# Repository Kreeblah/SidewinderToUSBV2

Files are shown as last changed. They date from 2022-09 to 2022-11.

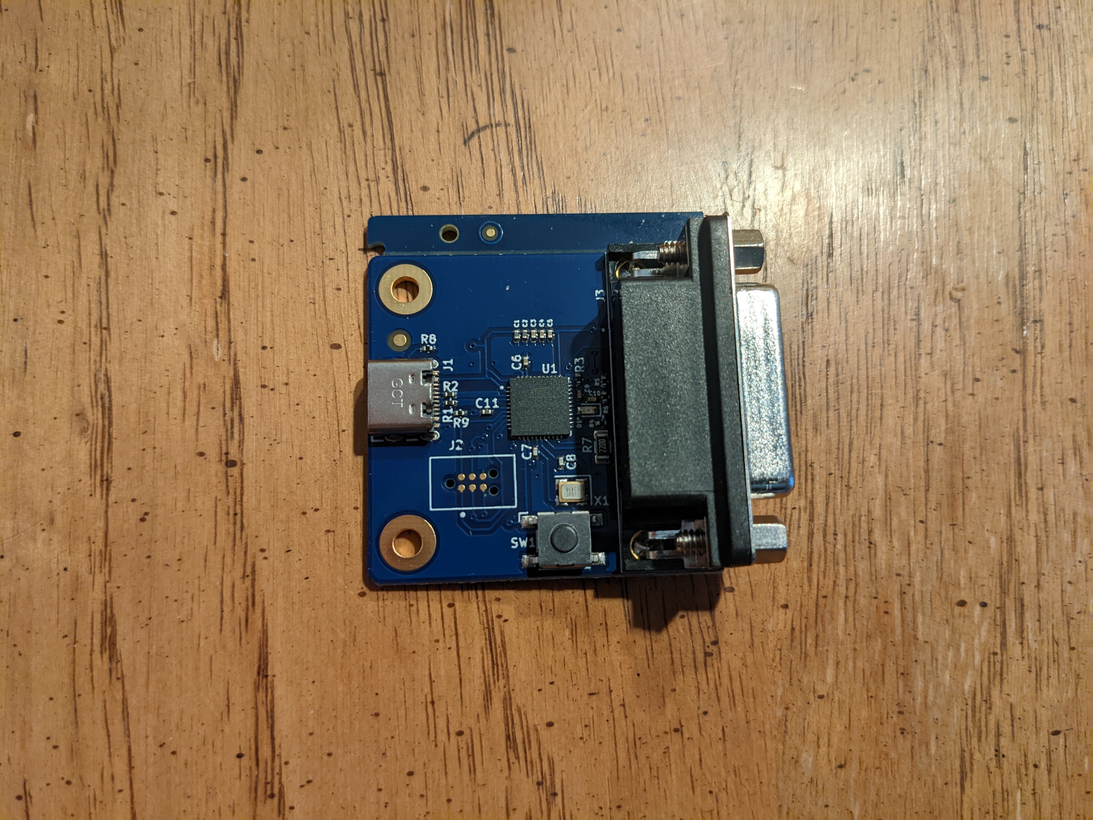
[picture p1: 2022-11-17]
Board_Front.jpg

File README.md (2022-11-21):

# SidewinderToUSBV2 (USB C version)
**NOTE:** The only BOM which has been actually manufactured and tested is the DigiKey BOM with PCBWay.  The other BOMs are available for convenience/reference, but should be double-checked for accuracy and compliance with assembly house requirements.

**NOTE 2:** The current parts shortage means that the microcontroller used in this design is in short supply.  I have successfully tested the design with an ATmega32u4RC-MU substituted for the original ATmega32u4-MU.  No changes need to be made to the programming or board design to substitute the part in.

This project is an integrated Sidewinder adaptor, which includes assembly files for various manufacturers.  This project originated as a combination of [the adapt-ffb-joy project](https://github.com/tloimu/adapt-ffb-joy) (minus the trim pots) with the [Teensy 2.0](https://www.pjrc.com/teensy/schematic.html) in order to remove the requirement for a comparatively expensive Teensy module and to make manufacture by a professional facility easier, with the intent of providing an open-source board that people can use to send off to have adaptors made.

Source code for the Sidewinder adaptor hexes can be found at [the adapt-ffb-joy project](https://github.com/tloimu/adapt-ffb-joy) and [the sw3dprousb project](https://code.google.com/archive/p/sw3dprousb/).  Programming can be done using a [Tag-Connect TC2030-IDC-NL](https://www.tag-connect.com/product/tc2030-idc-nl) and an AVR programmer capable of programming a Microchip (formerly Atmel) ATmega32U4 such as the [Pololu AVR Programmer v2.1](https://www.pololu.com/product/3172).

Licensing for the board is Creative Commons Attribution-ShareAlike 4.0 (CC BY-SA 4.0).

# Firmware

To use with various Sidewinder devices, there are three .hex files provided.  Only one of them can be flashed to the microcontroller at a time, so which one to use depends on which device you'll be using the adaptor with:

- 3DPro32u4-10.hex - Sidewinder Precision Pro, 3D Pro, 3D Pro Plus, or Force Feedback Pro (without force feedback support)
- adaptffbjoy-r54.hex - Sidewinder Force Feedback Pro (with force feedback support)
- adaptffbjoy-r54-patched.hex - Same as adaptffbjoy-r54.hex plus [some additional patches](https://github.com/Kreeblah/adapt-ffb-joy) (FFB strength calculation and a fix for the shift button)
- adaptffbjoy-r54-JayBee.hex - Another alternative patch set for adaptffbjoy-r54.hex, sourced from https://github.com/JayBee-git/adapt-ffb-joy
- Wheel.hex - Sidewinder Force Feedback Wheel

# Hardware

Schematic and PCB files for the board are provided in KiCad format.

Gerbers and POS files (for component placement) are included in the Production directory.  Note that the USB lines were calculated assuming 1 oz copper thickness.

BOMs for various assembly houses are also included in the Production directory.  All of the parts listed in the BOMs are RoHS-compliant.

Important components for users to be aware of are J1 (the USB C port), J3 (the gameport), and SW1 (the reset button).  For people who have these built themselves, J2 is the block of pads used for programming the AVR.

# Known Issues

- Some people have seen issues with FFB sticks sometimes not properly using FFB effects or getting stuck, even using the FFB-specific firmware.  For other people, though, it works fine.  I've been able to replicate the issue both on this adaptor and on one which uses the original Teensy 2.0-based design, so the behavior is at least consistent with the original design.  Some folks have seen some FFB improvements with Teensy 2.0-based designs by replacing one of 1nF capacitors with 1.5nF capacitors (C2 on the original schematic), but I haven't seen the same improvements when making the same change this board.  I'll need to test out other capacitance values and see whether any of them yield similar improvements on this design.
- Sometimes, people see some jitter between a couple of values in the X and Y axes when the stick isn't being touched.  This is an issue that exists both with this adaptor and the original design, as it's a firmware issue.  These adaptors report exactly what the joystick sends for data, which includes that jitter that some people observe.  A fix for this would require a firmware update to account for it in software, at which point, it would be fixed in these adaptors and the original adaptors.
- adaptffbjoy-r54.hex doesn't use the shift button properly.  It's supposed to act as a meta button to turn the eight other buttons into an effective sixteen buttons (one button with shift not pressed, and a different one with shift pressed), however it acts as a ninth button instead of a modifier for other buttons.  adaptffbjoy-r54-patched.hex includes a patch to fix this.

# Programming

## General

**Note:** The board should be disconnected from USB and from your joystick while programming it via an ISP.  To power it during programming, make sure your programmer is set to output 5V.

Programming the board using the above combo of programmer and connector can be done with [AVRDUDE](https://www.nongnu.org/avrdude/).  Fuses should be set to [low: 5F, high: 99, extended: C4, lockbit: FF](http://eleccelerator.com/fusecalc/fusecalc.php?chip=atmega32u4&LOW=5F&HIGH=99&EXTENDED=C4&LOCKBIT=FF).

If you're using the Pololu programmer mentioned above, then in order to get the path to the port your programmer is on, you can do this:

    pavr2cmd --prog-port

This will return a device port path which can be used as a parameter to AVRDUDE to program your board.

Regardless of which programmer you use, though, you'll need the path to your device, which you can then use with AVRDUDE:

    avrdude -c YOUR_PROGRAMMER_TYPE -P YOUR_DEVICE_PORT_PATH -p atmega32u4 -U flash:w:YOUR_HEX_FILE:i

In this example, `YOUR_HEX_FILE` could be one of the firmware files or the hex file for a bootloader.

If you're unsure of what value to use for `-c`, check with your programmer documentation.  If you need a list of what programmers are supported, you can use:

    avrdude -c ?

If you're using the Pololu programmer, you can combine the two above commands via a subcommand in bash, zsh, ksh, etc.:

    avrdude -c stk500v2 -P $(pavr2cmd --prog-port) -p atmega32u4 -U lfuse:w:0x5f:m -U hfuse:w:0x99:m -U efuse:w:0xc4:m -U flash:w:YOUR_HEX_FILE:i

Or, for csh:

    avrdude -c stk500v2 -P `pavr2cmd --prog-port` -p atmega32u4 -U lfuse:w:0x5f:m -U hfuse:w:0x99:m -U efuse:w:0xc4:m -U flash:w:YOUR_HEX_FILE:i

Or fish:

    avrdude -c stk500v2 -P (pavr2cmd --prog-port) -p atmega32u4 -U lfuse:w:0x5f:m -U hfuse:w:0x99:m -U efuse:w:0xc4:m -U flash:w:YOUR_HEX_FILE:i

## Using a bootloader

If you'd prefer to use a bootloader rather than flashing a firmware file directly to the flash area, you can flash any ATMega32U4-compatible bootloader you like via an ISP.  This will allow for changing which firmware file is being used via the board's USB connection, rather than needing to connect an ISP again, but may result in longer boot times.  So far, only the [LUFA](https://github.com/abcminiuser/lufa) CDC bootloader has been tested, which is included in the `Bootloader` directory of this project, but other bootloaders are likely to work.

If using the LUFA CDC bootloader, when the board is connected to a USB port, press and release the reset button (labeled SW1 on the board) to reset into the bootloader.  At this point, avrdude can be used to flash the firmware file of your choice (shown below as `YOUR_HEX_FILE`) with the following command:

    avrdude -p atmega32u4 -c avr109 -P YOUR_DEVICE_PORT -U flash:w:YOUR_HEX_FILE:i

**Note:** `YOUR_DEVICE_PORT` is the port which the board shows up on when in bootloader mode.  On macOS, this will be a /dev/tty.usbmodem device (e.g. `/dev/tty.usbmodem14201`).  On Windows, it's likely to be a COM port.  On Linux, it should be somewhere in the /dev/ttyACM device list (e.g. `/dev/ttyACM0`).

### LUFA CDC Compilation Options

If you'd like to compile your own copy of the LUFA CDC bootloader, you can get the source code [here](https://github.com/abcminiuser/lufa).  The CDC bootloader code is in the `Bootloaders/CDC` directory, where there's a makefile.  If you have the AVR GCC toolchain installed, you can build the bootloader by editing the makefile to use the following settings (leaving the other settings as is):

    MCU = atmega32u4
    ARCH = AVR8
    BOARD = TEENSY2
    F_CPU = 16000000
    F_USB = $(F_CPU)
    FLASH_SIZE_KB = 32
    BOOT_SECTION_SIZE_KB = 4

At that point, if you have the AVR GCC toolchain installed properly, running `make` should go through the build and generate a file named `BootloaderCDC.hex` which you can flash as your bootloader using an ISP.

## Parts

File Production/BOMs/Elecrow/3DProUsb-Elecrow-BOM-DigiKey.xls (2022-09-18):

3DProUsb BOM
Part | Value | Device | Package | Qty | Description | Remark
J1 | USB C PORT | USB C PORT | HYBRID SMD/THRU-HOLE | 1 | CONN RCP USB2.0 TYP C 24P SMD RA | GCT USB4105-GF-A
J2 | N/A | N/A | N/A | 1 | DO NOT POPULATE - NOT A PART | Tag-Connect TC2030-NL-FP
J3 | FEMALE | DA15 CONNECTOR | 15POS | 1 | D-SUB R/A 15 WAY SOCKET | Adam Tech DA15-SL-25
U1 | ATMEGA32U4-MU | ATMEGA32U4-MU | QFN50P700X700X100-45N | 1 | IC MCU 8BIT 32KB FLASH 44VQFN | Microchip ATMEGA32U4-MU
X1 | 16.00 MHZ, 10PF LOAD CAPACITANCE | CLOCK CRYSTAL | SMD | 1 | CRYSTAL 16.00 MHZ 10PF SMD | EPSON FA-238 16.0000MB-K3
SW1 | PUSH-BUTTON SWITCH | PUSH-BUTTON SWITCH | SMD | 1 | SWITCH TACTILE SPST-NO 0.05A 24V | Omron Electronics Inc-EMC Div B3FS-1000P
D1 | GREEN | LED | 0603 | 1 | LED GREEN CLEAR SMD | Lite-On Inc. LTST-C191KGKT
C1,C2,C11 | 1UF, 16V | CERAMIC CAPACITOR | 0402 | 3 | CAP CER 1UF 16V X5R 0402 | Taiyo Yuden EMK105BJ105KV-F
C3,C4,C5,C6 | 0.1UF, 25V | CERAMIC CAPACITOR | 0402 | 4 | CAP CER 0.1UF 25V X7R 0402 | Taiyo Yuden TMK105B7104KV-FR
C7,C8 | 10PF, 50V | CERAMIC CAPACITOR | 0402 | 2 | CAP CER 10PF 50V NP0 0402 | Taiyo Yuden UMK105CG100DV-F
C9,C10 | 1000PF, 50V | CERAMIC CAPACITOR | 0402 | 2 | CAP CER 1000PF 50V X7R 0402 | Taiyo Yuden UMK105B7102KV-F
R1,R2 | 22 OHM, 1%, 1/16W | THICK FILM RESISTOR | 0402 | 2 | RES SMD 22 OHM 1% 1/16W 0402 | Bourns Inc. CR0402-FX-22R0GLF
R3,R4 | 1 KOHM, 1%, 1/16W | THICK FILM RESISTOR | 0402 | 2 | RESTHINFILM 0402 1K00 1% 63MW TC | Bourns Inc. CRT0402-FZ-1001GST
R5,R6 | 2.2 KOHM, 5%, 1/16W | THICK FILM RESISTOR | 0402 | 2 | RES SMD 2.2K OHM 5% 1/16W 0402 | Bourns Inc. CR0402-JW-222GLF
R7 | 220 OHM, 1%, 1/4W | THICK FILM RESISTOR | 1206 | 1 | RES SMD 220 OHM 1% 1/4W 1206 | Bourns Inc. CR1206-FX-2200ELF
R8, R9 | 5.1 KOHM 0.1% 1/16W | THICK FILM RESISTOR | 0402 | 2 | RES SMD 5.1K OHM 0.1% 1/16W 0402 | Panasonic Electronic Components ERA-2APB512X

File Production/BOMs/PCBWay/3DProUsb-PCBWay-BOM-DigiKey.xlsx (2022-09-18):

 |  |  | Sidewinder To USB BOM
Item # | *Designator | *Qty | Manufacturer | *Mfg Part # | Description / Value | *Package/Footprint | Type | Your Instructions / Notes
1 | J1 | 1 | GCT | USB4105-GF-A | CONN RCP USB2.0 TYP C 24P SMD RA | SMD | HYBRID | DigiKey Part: 2073-USB4105-GF-ADKR-ND
2 | J2 | 1 | Tag-Connect | TC2030-NL-FP | DO NOT POPULATE - NOT A PART | N/A | N/A | DO NOT POPULATE - NOT A PART
3 | J3 | 1 | Adam Tech | DA15-SL-25 | D-SUB R/A 15 WAY SOCKET | 15POS | THRU-HOLE | DigiKey Part: 2057-DA15-SL-25-ND
4 | U1 | 1 | Microchip Technology | ATMEGA32U4-MU | IC MCU 8BIT 32KB FLASH 44VQFN | SMD | SMD | DigiKey Part: ATMEGA32U4-MU-ND
5 | X1 | 1 | EPSON | FA-238 16.0000MB-K3 | CRYSTAL 16.00 MHZ 10PF SMD | SMD | SMD | DigiKey Part: SER4046CT-ND
6 | SW1 | 1 | Omron Electronics Inc-EMC Div | B3FS-1000P | SWITCH TACTILE SPST-NO 0.05A 24V | SMD | SMD | DigiKey Part: SW423CT-ND
7 | D1 | 1 | Lite-On Inc. | LTST-C191KGKT | LED GREEN CLEAR SMD | 0603 | SMD | DigiKey Part: 160-1446-1-ND
8 | C1,C2,C11 | 3 | Taiyo Yuden | EMK105BJ105KV-F | CAP CER 1UF 16V X5R 0402 | 0402 | SMD | DigiKey Part: 587-2477-1-ND
9 | C3,C4,C5,C6 | 4 | Taiyo Yuden | TMK105B7104KV-FR | CAP CER 0.1UF 25V X7R 0402 | 0402 | SMD | DigiKey Part: 587-5476-1-ND
10 | C7,C8 | 2 | Taiyo Yuden | UMK105CG100DV-F | CAP CER 10PF 50V NP0 0402 | 0402 | SMD | DigiKey Part: 587-1947-1-ND
11 | C9,C10 | 2 | Taiyo Yuden | UMK105B7102KV-F | CAP CER 1000PF 50V X7R 0402 | 0402 | SMD | DigiKey Part: 587-1220-1-ND
12 | R1,R2 | 2 | Bourns Inc. | CR0402-FX-22R0GLF | RES SMD 22 OHM 1% 1/16W 0402 | 0402 | SMD | DigiKey Part: CR0402-FX-22R0GLFCT-ND
13 | R3,R4 | 2 | Bourns Inc. | CRT0402-FZ-1001GST | RESTHINFILM 0402 1K00 1% 63MW TC | 0402 | SMD | DigiKey Part: CRT0402-FZ-1001GSTCT-ND
14 | R5,R6 | 2 | Bourns Inc. | CR0402-JW-222GLF | RES SMD 2.2K OHM 5% 1/16W 0402 | 0402 | SMD | DigiKey Part: CR0402-JW-222GLFCT-ND
15 | R7 | 1 | Bourns Inc. | CR1206-FX-2200ELF | RES SMD 220 OHM 1% 1/4W 1206 | 1206 | SMD | DigiKey Part: CR1206-FX-2200ELFCT-ND
16 | R8, R9 | 2 | Panasonic Electronic Components | ERA-2APB512X | RES SMD 5.1K OHM 0.1% 1/16W 0402 | 0402 | SMD | DigiKey Part: P5.1KCNDKR-ND
Need a quick and accurante quote? Need an efficient production? Please read SMT Ordering Necessary Files & Info in 1 minute. Thank you very much! (https://www.pcbway.com/smt_ordering_guide.html)
Click for Instructions on How to Create a BOM (https://www.pcbway.com/blog/PCB_Assembly/How_to_Build_a_BOM__Bill_Of_Materials_.html)

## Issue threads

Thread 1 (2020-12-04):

Boards to purchase

AGTDesigns, 2020-12-04:
Hi! Do you still have boards to sell? I have a Sidewinder FFB Wheel with gameport that I would like to use with Win10, do you think it might work? How much would the board cost?
Thanks a lot!

Kreeblah, 2020-12-04:
I do still have some to sell, yes.

This hardware should be completely compatible with the original design, so I'd imagine it works as well as it would on the original adaptor (working except for the force feedback functionality), but since I don't own an FFB Wheel, I don't really have the means to test it myself.

If you're still interested in one or if you have some more questions, feel free to send me an e-mail.  You can reach me via the same username as here at Gmail.

Closed 2020-12-04.

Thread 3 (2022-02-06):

Jitter on all axes on FFB Pro, but only with FFB active - perhaps EU 60hz power?

KTeichel, 2022-02-06:
Hi,

I'm one of those using the adapter for an old Sidewinder Force Feedback Pro, and (like other users) I get visible jitter on all of the axes unless they are fully deflected.

I wanted to share my observations about this, so that hopefully it can help find a fix eventually.
I noticed that the jitter only happens with the power supply plugged in.
Being located in Germany, I thought that it might have something to do with the power line frequency being different in US (60hz) vs mostly the rest of the world (50hz); I haven't looked at a 60 vs 50 hz oscillation in comparison though.
On closer inspection, it is not simply the PSU being plugged in, it seems to be rather the question of whether or not Force Feedback is actually active: if I toggle everything (including spring center) off in a utility software, the jitter goes away.
The only effect where the jitter isn't always visible (not visible when I don't touch the stick, that is) is "friction" - I don't know how motor activation works for different effects, but maybe that tells us something?

Anyway, best regards and I hope this can be of any help.

NolanNicholson, 2023-01-26:
This issue is seemingly common to all Force Feedback Pro joysticks. I live in the US, and my stick behaves the same way. Others have even tested the joystick on a native Gameport card and found the same exact behavior - axis values jitter whenever the FFB motors are on.

It's unclear whether this is the result of aging (in which case it has occurred surprisingly consistently with basically all of these joysticks), or whether this jitter was always present and nobody originally noticed it. In any case, the USB adapter is highly unlikely to be at fault.

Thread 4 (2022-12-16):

buy them

Soliver84, 2022-12-16:
Hello I read here:
Alexhttps://www.descentbb.net/viewtopic.php?p=389914#p389914

That you still have some if you still have 2 pieces, I would like to buy them, starting with the best firmware.
I live in Germany and would of course pay for the shipping. PayPal.

Thaks
Alex

Kreeblah, 2022-12-20:
Hi there!

I do still have some, but unfortunately I had to stop shipping to the EU last year.  The new rule that took effect on 1 July 2021 requires that any packages sent to the EU have VAT already collected by a registered entity, and the paperwork involved in registering to collect VAT on behalf of the EU doesn't really make sense for me.

That said, if you contact rage76 in that thread, he's located in Germany, and may have some left.

Thanks!

Soliver84, 2022-12-21:
Unfortunately I don't have access to the forum because I can't manage the security question.

If you send it as a gift or test board, no tax will be charged.

or you can ask the user for me. please i need your help

Thanks

Closed 2022-12-20.

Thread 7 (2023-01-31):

[REQUEST] Compatibility with Necroware's GamePort Adapter firmware

Hedda, 2023-01-31:
Please consider looking into adding firmware compatibility or a firmware fork of Necroware's GamePort Adapter firmware:

https://github.com/necroware/gameport-adapter

https://github.com/necroware/gameport-adapter/blob/main/README.md

https://github.com/necroware/gameport-adapter/tree/main/firmware/gameport-adapter

Necroware's GamePort Adapter firmware does not yet support Force Feedback (though someone as recently started working on that for the Necroware's GamePort Adapter hardware), but it does have other advantages, such as being fully open-source licensed under the GPL-3.0 license and including support for many other retro joysticks and gamepads.

The downside to Necroware's GamePort Adapter firmware is that it currently requires the hardware to have a DIP-switch for changing controller mode, which is something that I do not personally think is a bad idea, however might be solved in a other manor, or otherwise add a DIP-switch to your next board design?

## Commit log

2020-09-05 Initial commit with PCBWay production files
    [3DProUsb-B_Cu.gbr, 3DProUsb-B_Mask.gbr, 3DProUsb-B_Paste.gbr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]
2020-09-05 Added fiducials and additional ground plate under microcontroller
    [3DProUsb-B_Cu.gbr, 3DProUsb-B_Mask.gbr, 3DProUsb-B_Paste.gbr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]
2020-09-05 Further extended ground pour
    [3DProUsb-B_Cu.gbr, 3DProUsb-B_Mask.gbr, 3DProUsb-B_Paste.gbr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]
2020-09-05 Removed travel distance for ground signals
    [3DProUsb-B_Cu.gbr, 3DProUsb-B_Mask.gbr, 3DProUsb-B_Paste.gbr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]
2020-09-05 Added stitching vias
    [3DProUsb-B_Cu.gbr, 3DProUsb-B_Mask.gbr, 3DProUsb-B_Paste.gbr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]
2020-09-05 Turned top layer into additional ground plane and added no connect labels to unused clock pins
    [3DProUsb-B_Cu.gbr, 3DProUsb-B_Mask.gbr, 3DProUsb-B_Paste.gbr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]
2020-09-05 Added ZIP of POS files and renamed Gerber ZIP
2020-09-06 Added production silkscreen
    [3DProUsb-B_Cu.gbr, 3DProUsb-B_Mask.gbr, 3DProUsb-B_Paste.gbr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]
2020-09-07 Added more explicit marking for LED polarity
    [3DProUsb-B_Cu.gbr, 3DProUsb-B_Mask.gbr, 3DProUsb-B_Paste.gbr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]
2020-09-07 Made LED polarity more explicit
    [3DProUsb-B_Cu.gbr, 3DProUsb-B_Mask.gbr, 3DProUsb-B_Paste.gbr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]
2020-09-09 Rounded the corners on the PCB
    [3DProUsb-B_Cu.gbr, 3DProUsb-B_Mask.gbr, 3DProUsb-B_Paste.gbr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]
2020-09-10 Added BOM for Seeed Studio
    [3DProUsb-SeeedStudio-BOM.xlsx]
2020-09-10 Added BOMs for Makerfabs and OSpcb
    [3DProUsb-Makerfabs-BOM.xlsx, 3DProUsb-OSpcb-BOM.xlsx]
2020-09-10 Moved BOMs to BOMs directory
    [3DProUsb-Makerfabs-BOM.xlsx, 3DProUsb-OSpcb-BOM.xlsx, 3DProUsb-PCBWay-BOM.xlsx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]
2020-09-10 Added BOM for PCBgogo
    [3DProUsb-PCBgogo-BOM.xlsx]
2020-09-11 Added BOM for Elecrow
    [3DProUsb-Elecrow-BOM.xls]
2020-09-13 Increased VCC track width
    [3DProUsb-B_Cu.gbr, 3DProUsb-B_Mask.gbr, 3DProUsb-B_Paste.gbr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]
2020-09-21 Corrected USB port error
    [3DProUsb-B_Cu.gbr, 3DProUsb-B_Mask.gbr, 3DProUsb-B_Paste.gbr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]
2020-09-21 Replaced Gerber ZIP
2020-09-23 Connected ground pins of clock
    [3DProUsb-B_Cu.gbr, 3DProUsb-B_Mask.gbr, 3DProUsb-B_Paste.gbr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]
2020-09-24 Moved vias away from silkscreens
    [3DProUsb-B_Cu.gbr, 3DProUsb-B_Mask.gbr, 3DProUsb-B_Paste.gbr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]
2020-09-25 Made missed VCC traces thicker
    [3DProUsb-B_Cu.gbr, 3DProUsb-B_Mask.gbr, 3DProUsb-B_Paste.gbr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]
2020-09-25 Moved USB port
    [3DProUsb-B_Cu.gbr, 3DProUsb-B_Mask.gbr, 3DProUsb-B_Paste.gbr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]
2020-09-25 Updated edge cuts
    [3DProUsb-B_Cu.gbr, 3DProUsb-B_Mask.gbr, 3DProUsb-B_Paste.gbr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]
2020-09-28 Removed X2 extensions
    [3DProUsb-B_Cu.gbr, 3DProUsb-B_Mask.gbr, 3DProUsb-B_Paste.gbr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]
2020-09-29 Added soldermask window between pin pads for USB port
    [3DProUsb-B_Cu.gbr, 3DProUsb-B_Mask.gbr, 3DProUsb-B_Paste.gbr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]
2020-10-17 Added LCSC BOM for PCBWay
    [3DProUsb-PCBWay-BOM-DigiKey.xlsx, 3DProUsb-PCBWay-BOM-LCSC.xlsx]
2020-10-21 Added note in readme about current project status.
2020-10-22 Added missing component and connections
    [3DProUsb-B_Cu.gbr, 3DProUsb-B_Mask.gbr, 3DProUsb-B_Paste.gbr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]
2020-10-23 New board layout. Made things smaller, removed large trenches, and calculated USB differential impedance.
    [3DProUsb-B_Cu.gbr, 3DProUsb-B_Mask.gbr, 3DProUsb-B_Paste.gbr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]
2020-10-23 Moved a few traces further from the board edge
    [3DProUsb-B_Cu.gbr, 3DProUsb-B_Mask.gbr, 3DProUsb-B_Paste.gbr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]
2020-10-23 Moved a couple vias and silkscreens
    [3DProUsb-B_Cu.gbr, 3DProUsb-B_Mask.gbr, 3DProUsb-B_Paste.gbr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]
2020-10-25 Calculated USB trace differential impedance
    [3DProUsb-B_Cu.gbr, 3DProUsb-B_Mask.gbr, 3DProUsb-B_Paste.gbr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]
2020-10-25 Relaxed USB differential pair a bit for cheaper manufacturing.
    [3DProUsb-B_Cu.gbr, 3DProUsb-B_Mask.gbr, 3DProUsb-B_Paste.gbr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]
2020-10-25 Adjusted design rule checker and adjusted tracks for validation.
    [3DProUsb-B_Cu.gbr, 3DProUsb-B_Mask.gbr, 3DProUsb-B_Paste.gbr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]
2020-11-27 Updated BOMs and README for tested board.
    [3DProUsb-Elecrow-BOM-DigiKey.xls, 3DProUsb-Elecrow-BOM-LCSC.xls, 3DProUsb-Elecrow-BOM.xls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]
2020-11-27 Added a photo of the working board
2020-12-01 Updated with fuse bits.
2020-12-01 Added info about how to compile the LUFA CDC bootloader for this board
2021-07-09 Updated readme with info about part substitutions and capacitance values
2022-03-24 Update to new KiCAD formats
    [3DProUsb.kicad_pcb, 3DProUsb.kicad_sch, 3DProUsb.sch]
2022-09-18 Initial USB C revision
    [3DProUsb-Elecrow-BOM-DigiKey.xls, 3DProUsb-Elecrow-BOM-LCSC.xls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]
2022-10-21 Don't cut the ground plane from under the USB pair
    [3DProUsb.kicad_pcb, 3DProUsb.kicad_sch]
2022-10-24 Revised layout
    [3DProUsb.kicad_pcb, 3DProUsb.kicad_sch]
2022-10-24 Updated layout
    [3DProUsb-B_Cu.gbr, 3DProUsb-B_Mask.gbr, 3DProUsb-B_Paste.gbr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]
2022-11-17 Update board photo for USB C model
2024-03-16 Update to KiCAD 8
    [3DProUsb.kicad_pcb, 3DProUsb.kicad_sch]
2026-08-30 Update KiCad version
